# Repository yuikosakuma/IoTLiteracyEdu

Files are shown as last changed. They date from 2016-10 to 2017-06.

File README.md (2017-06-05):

# IoT Literacy Education
This project intends to educate "IoT literacy" with Arduino, Processing, and Python.  
Components are ...  
Programs are based on XMASS projects by TadaMatz.

* Arduino  
	- mote
	- XBee Router
* Python
	- Controller for XBee 
	- XBee Coordinator
* Processing
	- Visualizer

## 勉強の手順

1. Arduinoのノードを作り、スタンドアローンで試す
2. XBeeの設定
	1. XBeeにテプラでIDを貼り、アドレスとの対応をメモっておく
	2. X-CTUのインストール
	3. X-CTUでFirmwareの設定(CoordinatorやRouter, PAN ID, API enable = 2)
4. XBeeの通信テスト
	1. 送信はArduinoプログラム（送信アドレスを合わせること）
	2. 受信
		1. X-CTUでやってみる
		3. Pythonでやってみる（Serialライブラリを使う）
3. Databaseの構築
	1. PostgreSQL、pgAdminのインストール
	2. テーブルを構築（flagtest, connectiontest）カラムもつくる
3. PythonによるDatabase操作を試す
4. センサデータを定期的にXBeeで送信し、Pythonで受信してDatabaseに蓄える
5. ProcessingによるDatabase操作を試す
6. ProcessingでDatabaseを読み、データを視覚化する

## Preparation
PostgreSQL must be installed. (Installation guide in Japanese: [http://www.dbonline.jp/postgresinstall/](http://www.dbonline.jp/postgresinstall/))  
PostgreSQL Server should be configurated  
Following 2 tables must be configurated. Please refer to ```sql/setup.sql``` also.    
Install `psycopg2` for python.

* connectiontest
	- nodeid(Primary key, Integer), xbeeaddr(Integer), temperature(Numeric), destinationid(Integer), votedcounter(Integer), name(text), lastupdate(Timestamp without time zone), sendflag(Integer), volume(Integer)
* flagtest
	- flagid(Primary key, Integer), name(Text), value(Integer), angle(Integer), led(Integer)

SQL handling library for Processing needs Processing-2.2.1.  
Updated!!(2016/10/6): I found the way to use BezierSQLib in Processing-3.2.1.  
I write down the way instruction to do it here.

(It should work in other Linux, I guess. And also, once you have the new compiled library, you can just copy the library under "Processing/libraries" where other libraries in)  

Step 1. Clone (or download ZIP) the repository from [https://github.com/fjenett/sql-library-processing](https://github.com/fjenett/sql-library-processing).  
Step 2. Change two lines in `build.xml`.  

```
around #L15. adapt "location" the same place where the processing.exe is in. 
Before:
<property name="processing.classes"  
	location="/Users/fjenett/Repos/processing/build/macosx/work/Processing.app/Contents/Resources/Java/" />
After:
<property name="processing.classes"  
	location="/usr/local/lib/processing-3.2.1" /> 

around #L18. adapt "location" the same place where the other libraries is in. 
Before:
<property name="processing" location="/Users/fjenett/Documents/Processing/libraries"/>   
After:
<property name="processing" location="/home/pi/sketchbook/libraries"/>   
```  

Step 3. execute `ant` command.  
Then you should be able to use BezierSQLib with Processing-3.

XBee must be API mode with escaping (API=2)  
Use XBee-Arduino library as "XBee" [https://github.com/andrewrapp/xbee-arduino](https://github.com/andrewrapp/xbee-arduino) and put this in the same directory

version1 uses "dip switch array", version2 uses "volume" for application 

### version1
### data packet payload
UplinkHeader : 'U'  
DownlinkHeader : 'D' 

#### Uplink : End device to Coodrinator
Unicast to Coordinator  
{UplinkHeader(1B,[0]), ID(1B,[1]), Temperature(4B,[2~5]), destinationID(1B,[6]), name(0 ~ 10B, [7~])} (7 ~ 17 bytes in total)  
Temperature is multiplied by 10, in example, "25.3C" is sent like "0253". In the same way, "9.3C" is sent as "0093".

#### Downlink : Coordinator to End device
Broadcast  
{DownlinkHeader(1B,[0]), votedCounter for ID:1(1B,[1]), voteCounter for ID:2(1B,[2]), ... , votedCounter of ID:20(1B,[20])} (21 bytes in total)  
Ex. "0123456789:;<=>?@ABC"  
value = (int)id + '0' (0x48)

### version2
### data packet payload
UplinkHeader : 'U'  
DownlinkHeader : 'D'  
LED\_INSTRUCTION : 'L'  
SERVO\_INSTRUCTION : 'S'  

#### Uplink : End device to Coodrinator
Unicast to Coordinator  
{UplinkHeader(1B,[0]), ID(1B,[1]), Temperature(4B,[2~5]), volume(4B,[6~9]), name(0 ~ 10B, [10~])} (10 ~ 20 bytes in total)  
Temperature is multiplied by 10, in example, "25.3C" is sent like "0253". In the same way, "9.3C" is sent as "0093".
Volume is supposed to have the raw value of analogRead() of Arduino (0 ~ 1024)

#### Downlink : Coordinator to End device
Broadcast  
value in flagtest table, 1 for LED, 2 for Servo  
packet for LED controll:  
{DownlinkHeader(1B,[0]), LED\_INSTRUCTION(1B, [1]), ON/OFF(1B, [2]} (3 bytes in total)  
Ex. "DL1"  
1 for ON, 0 for OFF
packet for LED controll:  
{DownlinkHeader(1B,[0]), SERVO\_INSTRUCTION(1B, [1]), Angle(3B, [2~4]} (5 bytes in total)  
Ex. "DS104"  
The value of angle should be from 0 ~ 179

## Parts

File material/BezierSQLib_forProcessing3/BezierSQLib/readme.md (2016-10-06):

--------------------------------------------------------------------------------

SQLibrary, a Processing library that wraps around JDBC drivers to let
you access MySQL, SQLite and PostgreSQL databases
    
--------------------------------------------------------------------------------

Latest release (same that is in Processing's library manager):
https://raw.github.com/fjenett/sql-library-processing/latest/release/BezierSQLib.zip
    
--------------------------------------------------------------------------------

It's not an ORM (and will not become one) but it has some handy features
since v0.2.0 that makes it easier to load and save objects to a database.

    setFromRow(object)
    saveToDatabase(object)
    insertUpdateIntoDatabase(table, columns, values)

See:
https://raw.github.com/fjenett/sql-library-processing/master/src/de/bezier/data/sql/SQL.java

--------------------------------------------------------------------------------

Parts of this library are available under their own licenses. These are
redistributed as downloaded from the original sources:

MySQL Connector/J (JDBC driver)
mysql-connector-java-3.1.8-bin.jar
http://dev.mysql.com/downloads/connector/j/
http://dev.mysql.com/downloads/connector/j/3.1.html
GPL, http://www.gnu.org/licenses/old-licenses/gpl-2.0.html

PostgreSQL JDBC driver
postgresql-8.3-604.jdbc3.jar
http://jdbc.postgresql.org/
http://jdbc.postgresql.org/download.html
BSD, http://jdbc.postgresql.org/license.html

SQLite JDBC driver
sqlite-jdbc-3.7.2.jar
http://code.google.com/p/sqlite-jdbc/
Apache License 2.0, http://www.apache.org/licenses/LICENSE-2.0
    
--------------------------------------------------------------------------------

https://github.com/fjenett/sql-library-processing

--------------------------------------------------------------------------------

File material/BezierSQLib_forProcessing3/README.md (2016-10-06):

BezierSQLib confirmed to work with Processing-3.2.1   
put `BezierSQLib` directory to the same place where the other libraries is in.

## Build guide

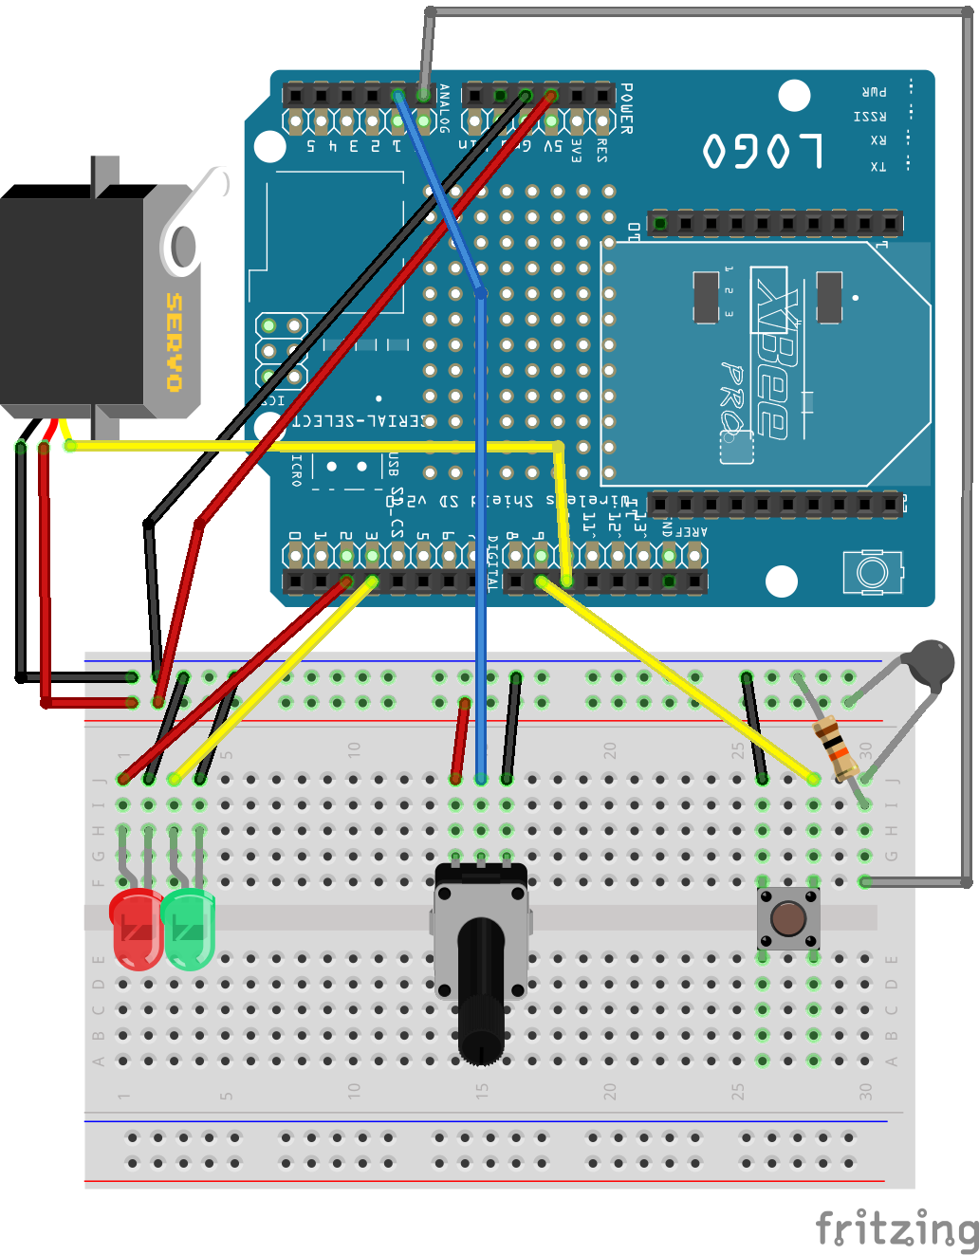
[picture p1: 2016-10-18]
version2/Fritzing/wiring.png

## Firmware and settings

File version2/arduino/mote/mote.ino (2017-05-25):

// mote.ino
// Program for Arduino version2
// Keio University Westlab 2016.10
// Author: Tada Matz

//<==== Please change according to an instruction
String MOTENAME = "hello"; //recommended to be between 1 ~ 10
int MOTEID = 1; //should be from 1 ~ 20
uint32_t DEST_ADDR_LSB = 0x415C081C; // LSB of XBee Coordinator Address
//====>Please change according to an instruction

#include "XBee.h"
#include "source.h"

Servo myservo;
MyXBee myxbee;
int oldButtonState = 0;
boolean receiveServoDataFlag = false;
int receiveLedState = 0;
unsigned long serialPreviousMillis;    //loop serial print
unsigned long clickLedPreviousMillis;
unsigned long servoPreviousMillis;

#define WITH_PERIODIC
#ifdef WITH_PERIODIC
unsigned long sendPastMillis = millis();
#define SEND_INTERVAL 1000
#endif

int currentAngle = 0;
#define WITH_SERVO_FOLLOWING
#ifdef WITH_SERVO_FOLLOWING
int lastVolumeValue = 0;
#endif

void setup() {
  Serial.begin(9600);

  serialPreviousMillis = millis();
  clickLedPreviousMillis = millis();
  servoPreviousMillis = millis();

  pinMode(RECEIVE_LED_PIN, OUTPUT);
  digitalWrite(RECEIVE_LED_PIN, HIGH);
  pinMode(CLICK_LED_PIN, OUTPUT);
  digitalWrite(CLICK_LED_PIN, HIGH);
  pinMode(BUTTON_PIN, INPUT_PULLUP);

  myservo.attach(SERVO_PIN); //attach(pin number(must be PWM pin), MIN pulse width, MAX pulse width)
  myservo.write(0);

  myxbee.init();
}

void loop() { //loop
  digitalWrite(RECEIVE_LED_PIN, receiveLedState);

  if (millis() - clickLedPreviousMillis >= CLICK_LED_ON_INTERVAL) digitalWrite(CLICK_LED_PIN, LOW);  //put off click LED
  if (receiveServoDataFlag && millis() - servoPreviousMillis >= SERVO_ON_INTERVAL) {
    receiveServoDataFlag = false;
    digitalWrite(CLICK_LED_PIN, LOW);  //put off click LED
  }

  //check receiving data
  myxbee.receiveXBeeData(myservo);

  //sending data
  if (clickDetection() == 1) {
    Serial.println(F("Button clicked"));
    digitalWrite(CLICK_LED_PIN, HIGH);
    clickLedPreviousMillis = millis();
    float tempTemperature = getTemperature(TEMP_SENSOR_PIN);
    int tempVolume = getVolume(VOLUME_PIN);
    char tempStr[1 + 1 + 4 + 4];
    sprintf(tempStr, "%c%c%04d%04d",
            UPLINK_HEADER,
            MOTEID + int(ID_PACKET_OFFSET),
            int(tempTemperature * 10),
            tempVolume);
    String temppayload = "";
    temppayload += tempStr + MOTENAME + "\n";
    myxbee.sendXBeeData(temppayload);
    Serial.print("temppayload: ");
    Serial.print(temppayload);
  }

#ifdef WITH_PERIODIC
  if (millis() - sendPastMillis > SEND_INTERVAL) {
    sendPastMillis += SEND_INTERVAL;
    float tempTemperature = getTemperature(TEMP_SENSOR_PIN);
    int tempVolume = getVolume(VOLUME_PIN);
    char tempStr[1 + 1 + 4 + 4];
    sprintf(tempStr, "%c%c%04d%04d",
            UPLINK_HEADER,
            MOTEID + int(ID_PACKET_OFFSET),
            int(tempTemperature * 10),
            tempVolume);
    String temppayload = "";
    temppayload += tempStr + MOTENAME + "\n";
    myxbee.sendXBeeData(temppayload);
    Serial.print("temppayload: ");
    Serial.print(temppayload);
  }
#endif

#ifdef WITH_SERVO_FOLLOWING
  if (!receiveServoDataFlag) {
    int tempVolume = getVolume(VOLUME_PIN);
    if (tempVolume != lastVolumeValue) {
      lastVolumeValue = tempVolume;
      currentAngle = (int)map(tempVolume, 0, 1023, 0, 165);
      myservo.write(currentAngle);
      delay(15);
    }
  }
#endif

  if (millis() - serialPreviousMillis > 1000) {  //loop seconds
    serialPreviousMillis += 1000;
    Serial.println(F("in a loop"));
  }
}

int clickDetection() { //click detection
  int buttonClicked = 0;
  int newButtonState = digitalRead(BUTTON_PIN);
  if (oldButtonState == HIGH && newButtonState == LOW) buttonClicked = 1; //button pressed. CAUTION pull up
  oldButtonState = newButtonState;
  return buttonClicked;
}

float getTemperature(int pin) { //Measure temperature, origined from Bob-san's program
  int v = 1023 - analogRead(pin);
  float res = (1023.0 / v) - 1;
  res = SERIESRESISTOR / res;
  float temp = (1 / (0.00096564 + (0.00021068 * log(res) ) + (0.000000085826 * ( pow( log(res) , 3))))) - 273.15;
  return temp;
}

int getVolume(int pin) { //measure volume value through analog pin
  return analogRead(pin);
}

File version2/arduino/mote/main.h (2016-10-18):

/*
 * main.h
 * Author: Tada Matz
 * Comment: define pins and interval
 */

#ifndef MAIN_H
#define MAIN_H

//button
#define BUTTON_PIN 9

//Click LED
#define CLICK_LED_PIN 3
#define CLICK_LED_ON_INTERVAL 1000

//Receive LED
#define RECEIVE_LED_PIN 2
#define RECEIVE_LED_ON_INTERVAL 1000

//packet
#define ID_PACKET_OFFSET '0'
#define UPLINK_HEADER 'U'
#define DOWNLINK_HEADER 'D'
#define LED_INSTRUCTION 'L'
#define SERVO_INSTRUCTION 'S'

//temperature sensor
#define TEMP_SENSOR_PIN A0
#define SERIESRESISTOR 10000

//volume
#define VOLUME_PIN A1

//Servo
#define SERVO_PIN 10
#define SERVO_ON_INTERVAL 5000

#endif

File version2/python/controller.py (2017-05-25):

#based on 160419TSIBPXMASSControllerBatteryRefineOverlapSaveDataAll
#To do: handle minus value of Thermister. This program does not stop but value could be crazy

import serial
import time
import array
import sys

import psycopg2
from psycopg2.extensions import adapt, register_adapter, AsIs
import datetime
import random

ID_PACKET_OFFSET = '0'
UPLINK_HEADER = 'U'
DOWNLINK_HEADER = 'D'
LED_INSTRUCTION = 'L'
SERVO_INSTRUCTION = 'S'

def readSerial(ser): #can process the Escape mode API = 2
    var = ord(ser.read())
    if(var == 0x7D):
        var = ord(ser.read()) ^ 0x20
    return var

def chrWithEscape(value):
    var = chr(value)
    if(value == 0x7E or value == 0x7D or value == 0x11 or value == 0x13):
        var = chr(0x7D) + chr(value ^ 0x20)
    return var

def makeZigBeeTransmitRequestPacket(dst64addrH, dst64addrL, dst16addr, payLoad): #Frame type = 0x10 packet sender
    length = 1 + 1 + 8 + 2 + 1 + 1 + len(payLoad)

    frameData = chr(0x10) #frameType
    frameData += chr(0x01) #frameID

    sp8 = chr(dst64addrH % 256) #dst64addr High
    dst64addrH = dst64addrH / 256
    sp7 = chr(dst64addrH % 256)
    dst64addrH = dst64addrH / 256
    sp6 = chr(dst64addrH % 256) 
    dst64addrH = dst64addrH / 256
    sp5 = chr(dst64addrH % 256)

    sp12 = chr(dst64addrL % 256) #dst64addr Low
    dst64addrL = dst64addrL / 256
    sp11 = chr(dst64addrL % 256)
    dst64addrL = dst64addrL / 256
    sp10 = chr(dst64addrL % 256)
    dst64addrL = dst64addrL / 256
    sp9 = chr(dst64addrL % 256)

    frameData += sp5 + sp6 + sp7 + sp8 + sp9 + sp10 + sp11 + sp12

    frameData += chr((dst16addr / 256) % 256) #dst16addr
    frameData += chr(dst16addr % 256)

    frameData += chr(0x00) #Broadcast radius
    frameData += chr(0x00) #options

    frameData += payLoad #data payload

    checksum = 0 #checksum calculation
    for i in frameData:
        checksum += ord(i)
    checksum = 0xFF - ord(chr(checksum % 256))
    # print "checksum:", checksum

    tempPacket = chr((length / 256) % 256) + chr(length % 256) + frameData + chr(checksum)

    sendPacket = chr(0x7E)
    for i in tempPacket:
        sendPacket += chrWithEscape(ord(i))

    print "===> send", length, "bytes data. Data: ", payLoad
    # print "     hex:",
    # for i in sendPacket:
    #     print hex(ord(i)),
    # print ""

    return sendPacket

if __name__ == "__main__":
  #database intialization <===
  print "database initialization start"
  conn = psycopg2.connect(host="localhost", database="iotedu", user="postgres", password="mypgsql")
  print "database initialization end"
  #===>database
  
  #<=== Serial port initialization
  print "serial port initialization start"
  port = '/dev/ttyUSB0' #XBee Explorer via USB that is for raspberry pi
  # port = 'COM11' #XBee Explorer
  serialPort = serial.Serial(port, 9600, timeout = 1)
  print port + " is opend"
  time.sleep(2) #wait for establishing stable serial connection
  print "serial port initialization end"
  #===> Serial port initialization

  #<=== initial data printing
  cur = conn.cursor()
  cur.execute("SELECT * FROM connectiontest ORDER BY nodeid")
  result = cur.fetchall()
  print result
  if result == []:
    print "oh... no data"
  else:
    print "yeah... we have data"
    for row in result:
      print row
  conn.commit()
  cur.close()  
  #===> initial data printing

  try:
    while True:
      #<=== packet receiving
      if serialPort.inWaiting() > 0: #if something is in serial port
        var = readSerial(serialPort)
        if(var == 0x7E): #and if this is the XBee packet

          frameData = []
          frameData.append(var)

          frameData.append(readSerial(serialPort))
          frameData.append(readSerial(serialPort))
          frameLength = frameData[1] * 256 + frameData[2]
          # print "<=== received hex:", hex(var), hex(frameData[1]), hex(frameData[2]),

          counter = 0
          checksumsum = 0
          while counter < frameLength + 1:
            var = readSerial(serialPort)
            frameData.append(var)
            checksumsum += var
            # print hex(var),
            counter += 1
            # print ""

          #print "frameLength:", frameLength,
          #print "frameData:", frameData
          #print "checksumsum:", hex(checksumsum)

          frameType = frameData[3]
          # print "frameType:", hex(frameType)

          if(frameType == 0x90): #ZigBee Receive Packet Response
            #print "<=== ZigBee Receive Packet: ",
            src64addrH = 0
            for i in range(0,4):
              src64addrH += frameData[i + 4] * pow(256,(3 - i))
              src64addrL = 0
            for i in range(0,4):
              src64addrL += frameData[i + 8] * pow(256,(3 - i))
              src16addr = frameData[12] * 256 + frameData[13]
              receiveOptions = frameData[14]
              receiveData = []
            for i in range(15, frameLength + 3):
              receiveData.append(frameData[i])
            #print "str(bytearray(receiveData)):", str(bytearray(receiveData))

            payloadType = receiveData[0]
            # print "payloadType: ", str(hex(payloadType)), "chr(payloadType): ", str(chr(payloadType))
            if payloadType == ord(UPLINK_HEADER) and len(receiveData) > 7:
              tmp_id = int(receiveData[1] - ord(ID_PACKET_OFFSET))
              tmp_temperature = float(receiveData[2] - ord(ID_PACKET_OFFSET)) * 100 + float(receiveData[3] - ord(ID_PACKET_OFFSET) ) * 10 + float(receiveData[4] - ord(ID_PACKET_OFFSET)) * 1 + float(receiveData[5] - ord(ID_PACKET_OFFSET)) * 0.1
              tmp_volume = int(receiveData[6] - ord(ID_PACKET_OFFSET)) * 1000 + int(receiveData[7] - ord(ID_PACKET_OFFSET) ) * 100 + int(receiveData[8] - ord(ID_PACKET_OFFSET)) * 10 + int(receiveData[9] - ord(ID_PACKET_OFFSET)) * 1
              tmp_name = receiveData[10:len(receiveData)]
              tmp_name_str = ""
              for c in tmp_name:
                tmp_name_str += chr(c)
              
              print "len:", frameLength, "data:", str(bytearray(receiveData)).strip()
              print  "id:", tmp_id, "temp:", tmp_temperature, "volume:", tmp_volume, "name:", tmp_name_str.strip()

              #update database
              cur = conn.cursor()
              cur.execute("UPDATE connectiontest SET temperature=%s, volume=%s, xbeeaddr=%s, name=%s, lastupdate=%s WHERE connectiontest.nodeid=%s", \
                [tmp_temperature, tmp_volume, src64addrL, tmp_name_str.strip(), datetime.datetime.utcnow(), tmp_id])
              conn.commit()
              cur.close()
      #===> packet receiving
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

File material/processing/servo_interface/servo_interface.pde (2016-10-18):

int LEDstate = 0;
float theta = -PI;
boolean servo_locked = true;
int flag_on = 0;
int flag_off = 0;
boolean ONrectOver = false;
boolean OFFrectOver = false;
boolean servoOver = false;
PImage img;

void setup() {
  size(600, 800);
  surface.setResizable(true);

  //***** Make a new instance of a PImage by loading an image file *****
  img = loadImage("servo_bg.png");
}

void draw() {
  //***** If LED BUTTON IS PUSHED *****
  if (flag_on == 1) {
    //api_send_LED();
    flag_on = 0;
  } else if (flag_off == 1) {
    //api_send_LED();
    flag_off = 0;
  }

  updatedisplay();
}

void updatedisplay() {  
  float w = (float)width;
  float h = (float)height;
  float center_x = w/2;
  float center_y = h*3/8;
  float r = w/4;
  float d2 = w/40;
  float end_x = 0.0;
  float end_y = 0.0;

  float ONrectX = w*29/120; //145;      //Rect X Position
  float ONrectY = h*3/4; //600;      //Rect Y Position
  float ONrectSize = w/12; //50;    //Rect Size

  float OFFrectX = w*61/120; //305;      //Rect X Position
  float OFFrectY = h*3/4;      //Rect Y Position
  float OFFrectSize = w/12;    //Rect Size

  //***** If Unservo_locked, Update Position *****
  if (servo_locked == false) {
    float theta_tmp = atan2(mouseY - center_y, mouseX - center_x);
    if (-PI <= theta_tmp && theta_tmp <= 0) theta = theta_tmp;
  }
  end_x = cos(theta) *  r + center_x;
  end_y = sin(theta) * r + center_y;

  if (overRect(ONrectX, ONrectY, ONrectSize*3, ONrectSize) ) {
    ONrectOver = true;
  } else {
    ONrectOver = false;
  }

  if (overRect(OFFrectX, OFFrectY, OFFrectSize*3, OFFrectSize) ) {
    OFFrectOver = true;
  } else {
    OFFrectOver = false;
  }

  background(255);
  image(img, 0, 0, w, h*3/4);
  //***** Draw Servo Image *****
  fill(10);
  rect(w*5/12, h*3/16, w/6, h/4); //  rect(250, 150, 100, 200);
  fill(40);
  rect(w*5/12, h*3/20, w/6, h*3/80); //  rect(250, 120, 100, 30);
  rect(w*5/12, h*7/16, w/6, h*3/80);  //rect(250, 350, 100, 30);
  fill(255);
  ellipse(w/2, h*27/160, w*3/120, h*3/160); //  ellipse(300, 135, 15, 15);
  ellipse(w/2, h*73/160, w*3/120, h*3/160);//  ellipse(300, 365, 15, 15);
  fill(40);
  ellipse(center_x, center_y, w*18/120, h*18/160);//  ellipse(center_x, center_y, 90, 90);
  fill(255);
  strokeWeight(w*5/120);//25);
  stroke(200);
  line(center_x, center_y, end_x, end_y);
  fill(255, 100, 100);
  noStroke();
  ellipse(end_x, end_y, d2, d2);

  //***** Draw LED Image *****
  fill(255, 0, 0);
  ellipse(w/2, h*7/8, w/12, w/12); //  ellipse(300, 700, 50, 50);

  if (LEDstate == 1) {
    fill(255, 0, 0, 80);
  } else {
    fill(0, 255, 255, 90);
  }
  ellipse(w/2, h*7/8, w/12, w/12);//  ellipse(300, 700, 50, 50);

  //***** Draw LED Switch Image
  if (LEDstate == 1) fill(255, 0, 0);
  else fill(200);
  rect(ONrectX, ONrectY, ONrectSize*3, ONrectSize);
  if (LEDstate == 0) fill(0, 0, 255);
  else fill(200);
  rect(OFFrectX, OFFrectY, OFFrectSize*3, OFFrectSize);

  textSize(w*4/100); //24);
  textAlign(CENTER);
  fill(255, 255, 255);
  text("ON", w*44/120, h*125/160); //  text("ON", 220, 625);
  text("OFF", w*76/120, h*125/160); //  text("OFF", 380, 625);
}

void mousePressed()
{
  if ( overServo() ) {
    //***** Unlock Position *****
    servo_locked = false;
  }

  if (ONrectOver) {
    flag_on = 1;
    LEDstate = 1;
  }
  if (OFFrectOver) {
    flag_off = 1;
    LEDstate = 0;
  }
}

void mouseReleased()
{

  //***** Lock Position *****
  servo_locked = true;

  //***** Calculate Angle *****
  if (-PI <= theta && theta <= 0)
  {
    float temp = degrees(theta) + 180;
    int tx = (int)temp;
    //***** Broadcast Data *****
    println(tx);
    //api_send(tx);
  }
}

//***** Check if Over Rect *****
boolean overRect(float x, float y, float width, float height) 
{
  if (mouseX >= x && mouseX <= x+width && 
    mouseY >= y && mouseY <= y+height) {
    return true;
  } else {
    return false;
  }
}

//***** Check if Over Rect *****
boolean overServo() 
{
  if (mouseX >= 0 && mouseX <= 600 && 
    mouseY >= 0 && mouseY <= 600) {
    return true;
  } else {
    return false;
  }
}

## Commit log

2016-09-27 add servo functions and made it!!!
2016-09-27 add fritzing file
    [wiring.fzz]
2016-09-27 modify wiring
    [wiring.fzz]
2016-10-01 modify for text
    [wiring.fzz]
2016-10-06 update to run in raspberry pi
2016-10-06 add button
2016-10-06 modify button
2016-10-06 chagne for Raspberry Pi
2016-10-07 adjust button size but not respond
2016-10-07 make dynamic button works
2016-10-07 adapt to raspberry pi display
2016-10-07 periodic sending arduino
2016-10-18 add version 2
    [wiring.fzz]
2016-10-18 add volume and servo meter following
2016-10-18 apply servo to visualizer
2016-10-18 finish to make servo_interface
2016-10-18 separate led instruction and servo insturction
2016-10-18 allow Led and Servo controll from coodinator
2016-10-18 update wiring
    [wiring.fzz]
